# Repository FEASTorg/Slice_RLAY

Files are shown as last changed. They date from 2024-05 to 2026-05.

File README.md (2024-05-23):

<div align="center">
  <!-- Title: -->
  <a href="https://github.com/uwo-fast">
    
  </a>
  <h2><a href="https://github.com/uwo-fast/Slice_RLAY"> Slice RLAY </a></h2>
  <!-- Labels: -->
  <!-- First row: -->
  <a href="https://github.com/uwo-fast/.github/blob/main/collaborating.md">
    
  </a>
  <a href="https://github.com/uwo-fast/.github/blob/main/contributing.md">
    
  </a>
  <a href="https://www.appropedia.org/Category:FAST_literature_reviews">
    
  </a>
  <a href="https://certification.oshwa.org/">
    
    <!-- img src="https://img.shields.io/badge/OSHWA-Certified-darkgreen?style=flat-square" height="20" alt="OSHWA" -->       <!-- img src="https://img.shields.io/badge/OSHWA-Pending-darkorange?style=flat-square" height="20" alt="OSHWA" -->
  </a>
  <a href="https://osf.io/">
    
  </a>
  <a href="https://doi.org">
    
  </a>
  <!-- Second row: -->
  <br>
  <a href="https://github.com/uwo-fast/Slice_RLAY/blob/main/LICENSE">
    
  </a>
  <a href="https://github.com/uwo-fast/Slice_RLAY">
    
  </a>
  <a href="https://github.com/uwo-fast/Slice_RLAY/issues">
    
  </a>
  <a href="https://github.com/uwo-fast/Slice_RLAY/network/members">
    
  </a>
  <a href="https://github.com/uwo-fast/Slice_RLAY/stargazers">
    
  </a>
  <!-- Short description: -->
  <h3>4-Channel Relay Slice for BREAD.</h3>
</div>

## Introduction
[Provide a brief introduction to the project, including the motivation and goals. Explain the significance and context of the research.]

## Project Overview
[Describe the project in more detail. This section can be split into subsections if necessary.]

## Installation
[Provide instructions for installing any necessary software or hardware components.]

## Usage
[Explain how to use the project. Include examples and screenshots if applicable.]

### Basic Usage
[Provide basic usage instructions.]

### Advanced Usage
[Provide advanced usage instructions, including any optional features or configurations.]

## Documentation
[Link to the detailed documentation if available. Provide instructions on how to access and navigate the documentation.]

## Contributing
[Explain how others can contribute to the project. Include guidelines for submitting issues, pull requests, and any coding standards.]

### Code of Conduct
[Link to the project's code of conduct if available.]

## License
[State the license under which the project is distributed. Include a link to the full license text.]

## Acknowledgements
[Acknowledge any contributors, collaborators, funding sources, or organizations that supported the project.]

## Contact
[Provide contact information for the project maintainer(s) or lead researcher(s). Include an email address or a link to a contact form.]

---

<div align="center">
  <p>
    
    
  </p>
</div>

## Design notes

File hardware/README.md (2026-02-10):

# Broadly Reconfigurable and Expandable Automation Device (BREAD) -- Slice Datasheet: **Relay** Slice (SLC-**RLAY**)

## Short Device Description

This device controls 4 relay channels via the Arduino, and receives
analog signals (optionally) as feedback.

## Quick Information

Device at a Glance

---

Short title Relay Slice
Part \# SLC-RLAY
Repository Link Link to OSF or other repository
Academic Paper DOI DOI link to published paper
Device Cost Monetary cost of the device
Assembly Difficulty Medium. Millable.
Application Area Controls, Power Monitoring

---

Device Connections

J2 -- Relay Output 1

---

Pin \# Description Rating
1 Normally closed switch of relay 277 VAC, 30V DC, 3A
2 Normally open switch of relay 277 VAC, 30V DC, 10A AC, 5A DC
3 Common pin N/A

---

J2 -- Relay Output 2

---

Pin \# Description Rating
1 Normally closed switch of relay 277 VAC, 30V DC, 3A
2 Normally open switch of relay 277 VAC, 30V DC, 10A AC, 5A DC
3 Common pin N/A

---

J2 -- Relay Output 3

---

Pin \# Description Rating
1 Normally closed switch of relay 277 VAC, 30V DC, 3A
2 Normally open switch of relay 277 VAC, 30V DC, 10A AC, 5A DC
3 Common pin N/A

---

J2 -- Relay Output 4

---

Pin \# Description Rating
1 Normally closed switch of relay 277 VAC, 30V DC, 3A
2 Normally open switch of relay 277 VAC, 30V DC, 10A AC, 5A DC
3 Common pin N/A

---

## Commands

---

**Write Switch(es) **(no significant returns)  
 **Byte**: Address **Bit**: 1 **Float: **Target Temp **Float: **Ramp Rate (d/m)
**Timed Write** (no significant returns)  
 **Byte**: Address **Bit**: 0 **Float: **0 **Float: **0
Analog Read (Returns selected voltages from analog feedback)

---

## Schematic

## Bill of Materials

---

Designator Description Quantity Cost / part URL
U1-4 Optocouplers 4 0.51 <https://www.digikey.com/short/5fmc702d>
RV1-4 10k Trimmer Potentiometer 4 4.16 <https://www.digikey.com/short/ftm98v7t>
R1-4 1k 1206 Packaging Resistor 4 0.1 <https://www.digikey.com/short/d1dmzmbb>
K1-4 G5Q1 SPDT Relay 4 1.52 <https://www.digikey.com/short/vj4jr0vq>
J6 01x04 1/10" Pitch Terminal Block 1 2.75 <https://www.digikey.com/short/rnm0hhhn>
J2-5 01x03 1/10" Pitch Terminal Block 4 2.06 <https://www.digikey.com/short/71d77cj2>
D5-8 5.1V Zener Diode 4 0.22 <https://www.digikey.com/short/tvbtwpmt>
D1-4 Standard THT Diode 4 0.21 <https://www.digikey.com/short/tp4mrn5q>
C1-2 10 µF 1206 Packaging Ceramic Capacitor 4 0.64 <https://www.digikey.com/short/2ffb0248>
A1 Arduino Nano 1 22.00 <https://www.digikey.com/en/products/detail/arduino/A000005/2638989>
J1 01x10 Female Header Pins 1 0.79 <https://www.digikey.com/short/23bfwwjh>

---

## Construction & Fabrication

List any tools that are required and short guide on the order which
parts should be soldered / assembled. Be sure to note any specialized
methods and point out components that may easily be soldered in the
incorrect orientation. Additionally include at least one picture of the
assembled board (include both sides if there are components on both
sides).

\[Image of the assembled Circuit Board\]

Fig #. Subtitle should go here.

## Configuration & Calibration

Include a list of default jumper and potentiometer positions:

Hardware Positions

- Turn P1 to be roughly 50%
- Turn P2 to be completely closed (turn clockwise until potentiometer
  clicks)
- Place a jumper to short out J3. Etc...

Detail any key parameters the end-user may want to adjust in the
firmware, and if there are any special instructions before programming
the Slice.

Tools Required For Calibration

- An oscilloscope with at least 15Mhz sampling
- A multimeter. Etc...

List all of the tools / instruments required for calibration. Provide a
detailed & step by step guide on how to calibrate (or validate) each
unique type of channel on the card. Include what variables in the
firmware may need to be adjusted (and when). Attach a wiring diagram for
each relevant calibration circuit.

\[Image of the calibration circuit\]

Fig #. Subtitle should go here.

## Usage & Constraints

List the relevant constraints for each type of channel on the card.
These parameters may be quantities like max current, max voltage,
frequency, sampling frequency, etc.

List an example wiring diagram of the slice in use, as well as some
suggested applications

\[Image of the example usage wiring diagram\]

Fig #. Subtitle should go here.

## General Comments on Slice

This section is intended as a catch-all for any topics that are relevant
to the Slice that don't fit in any other category.

## Revision Notes

- Rev 0 -- Initial document release (DATE HERE)

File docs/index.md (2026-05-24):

---
title: "Slice RLAY Documentation"
description: "Overview and entry page for Slice RLAY project documentation."
nav_exclude: true
---

Welcome to the Slice RLAY project documentation.

## Board Renders

<figure style="display:inline-block; text-align:center; margin:10px;">
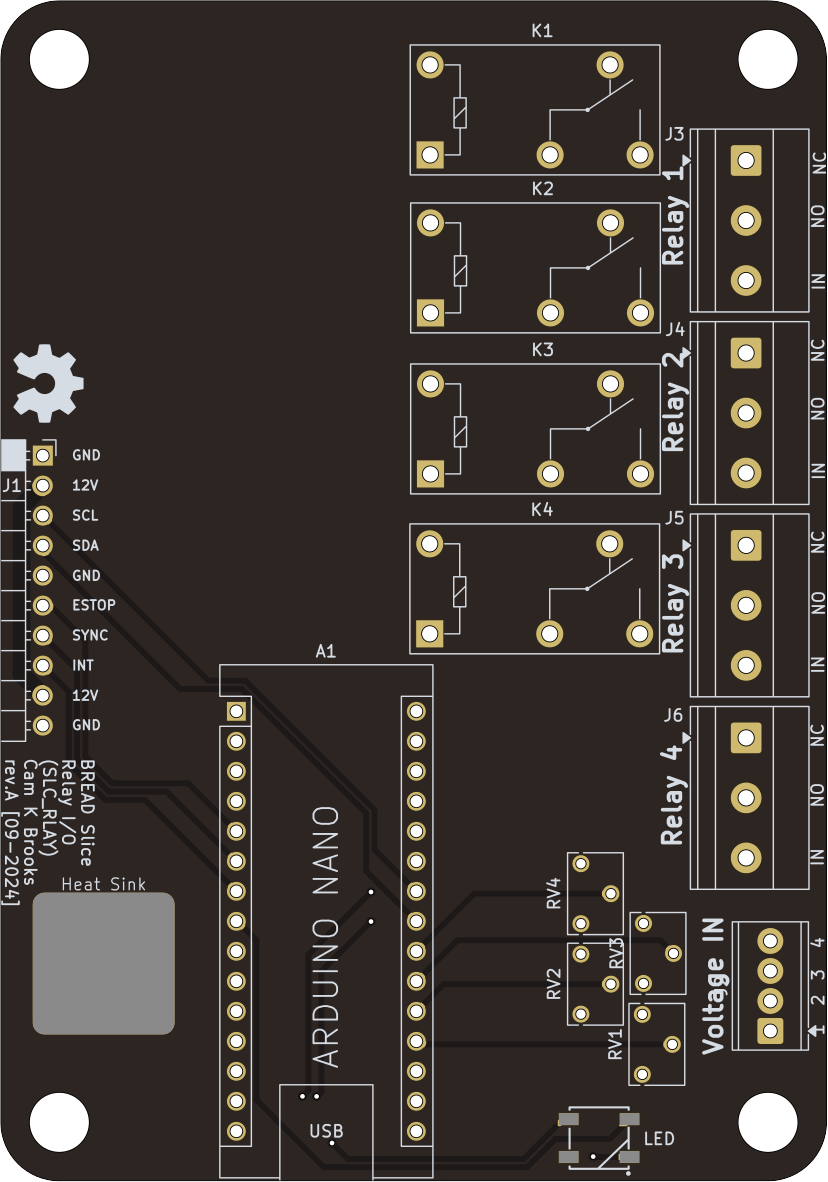
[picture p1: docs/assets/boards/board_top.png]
Board Top
  
  <figcaption>Top</figcaption>
</figure>

<figure style="display:inline-block; text-align:center; margin:10px;">
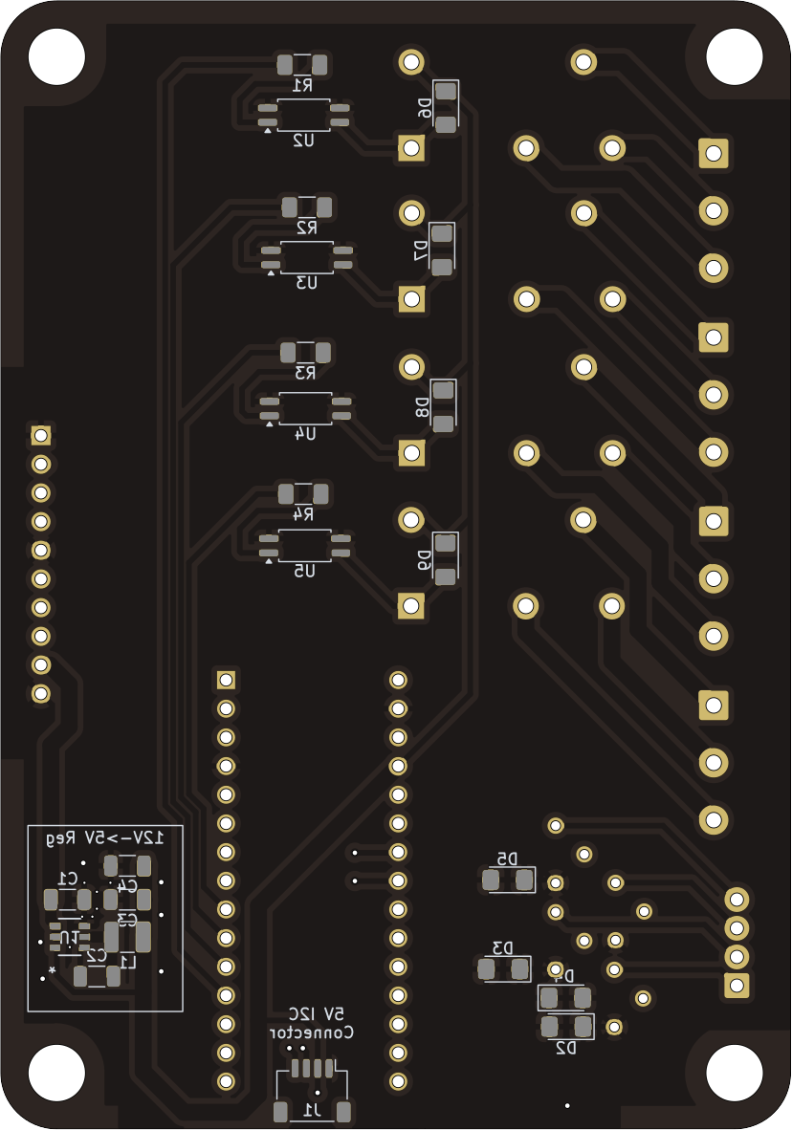
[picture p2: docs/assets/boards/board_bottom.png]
Board Bottom
  
  <figcaption>Bottom</figcaption>
</figure>

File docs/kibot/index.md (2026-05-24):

Slice RLAY KiBot Outputs
============================

Generated: 2026-05-24 at 16:19:26 UTC

## Artifacts

- [Schematic.pdf](./Schematic.pdf)
- [PCB.pdf](./PCB.pdf)
- [kibot.log](./kibot.log)
- [BREAD_Slice-bom.html](./BREAD_Slice-bom.html)
- [BREAD_Slice-ibom.html](./BREAD_Slice-ibom.html)

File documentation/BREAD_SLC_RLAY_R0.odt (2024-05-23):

# Broadly Reconfigurable and Expandable Automation Device (BREAD) – Slice Datasheet: Relay Slice (SLC-RLAY)

By: Nicholas Whisman (ngwhisma@mtu.edu) – Revision 0, on 17. May 2021

## Short Device Description

This device controls 4 relay channels via the Arduino, and receives analog signals (optionally) as feedback.

## Quick Information

Device at a Glance

Short title | Relay Slice
Part # | SLC-RLAY
Repository Link | Link to OSF or other repository
Academic Paper DOI | DOI link to published paper
Device Cost | Monetary cost of the device
Assembly Difficulty | Medium. Millable.
Application Area | Controls, Power Monitoring

Device Connections

J2 – Relay Output 1

Pin # | Description | Rating
1 | Normally closed switch of relay | 277 VAC, 30V DC, 3A
2 | Normally open switch of relay | 277 VAC, 30V DC, 10A AC, 5A DC
3 | Common pin | N/A

J2 – Relay Output 2

Pin # | Description | Rating
1 | Normally closed switch of relay | 277 VAC, 30V DC, 3A
2 | Normally open switch of relay | 277 VAC, 30V DC, 10A AC, 5A DC
3 | Common pin | N/A

J2 – Relay Output 3

Pin # | Description | Rating
1 | Normally closed switch of relay | 277 VAC, 30V DC, 3A
2 | Normally open switch of relay | 277 VAC, 30V DC, 10A AC, 5A DC
3 | Common pin | N/A

J2 – Relay Output 4

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

## Commands

Write Switch(es) (no significant returns)
Byte: Address | Bit: 1 | Float: Target Temp | Float: Ramp Rate (d/m)
Timed Write (no significant returns)
Byte: Address | Bit: 0 | Float: 0 | Float: 0
Analog Read (Returns selected voltages from analog feedback)

## Schematic

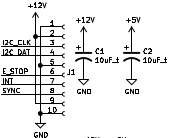
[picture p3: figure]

Figure 1: BREAD Connection Port + Power Capacitors

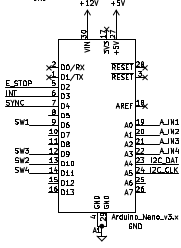
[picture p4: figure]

Figure 2: Arduino Nano

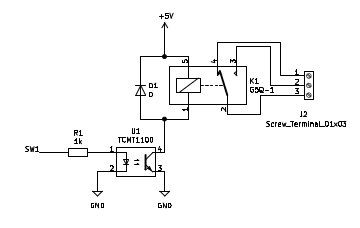
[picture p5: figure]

Figure 3: One of Four Relay Channels

Figure 4: One of Four Analog Input Paths

Figure 5: Feedback Input Port

## Bill of Materials

Designator | Description | Quantity | Cost / part | URL
U1-4 | Optocouplers | 4 | 0.51 | https://www.digikey.com/short/5fmc702d
RV1-4 | 10k Trimmer Potentiometer | 4 | 4.16 | https://www.digikey.com/short/ftm98v7t
R1-4 | 1k 1206 Packaging Resistor | 4 | 0.1 | https://www.digikey.com/short/d1dmzmbb
K1-4 | G5Q1 SPDT Relay | 4 | 1.52 | https://www.digikey.com/short/vj4jr0vq
J6 | 01x04 1/10” Pitch Terminal Block | 1 | 2.75 | https://www.digikey.com/short/rnm0hhhn
J2-5 | 01x03 1/10” Pitch Terminal Block | 4 | 2.06 | https://www.digikey.com/short/71d77cj2
D5-8 | 5.1V Zener Diode | 4 | 0.22 | https://www.digikey.com/short/tvbtwpmt
D1-4 | Standard THT Diode | 4 | 0.21 | https://www.digikey.com/short/tp4mrn5q
C1-2 | 10 µF 1206 Packaging Ceramic Capacitor | 4 | 0.64 | https://www.digikey.com/short/2ffb0248
A1 | Arduino Nano | 1 | 22.00 | https://www.digikey.com/en/products/detail/arduino/A000005/2638989
J1 | 01x10 Female Header Pins | 1 | 0.79 | https://www.digikey.com/short/23bfwwjh

## Construction & Fabrication

List any tools that are required and short guide on the order which parts should be soldered / assembled. Be sure to note any specialized methods and point out components that may easily be soldered in the incorrect orientation. Additionally include at least one picture of the assembled board (include both sides if there are components on both sides).

[Image of the assembled Circuit Board]

Fig #. Subtitle should go here.

## Configuration & Calibration

Include a list of default jumper and potentiometer positions:

Hardware Positions

- Turn P1 to be roughly 50%
- Turn P2 to be completely closed (turn clockwise until potentiometer clicks)
- Place a jumper to short out J3. Etc…

Detail any key parameters the end-user may want to adjust in the firmware, and if there are any special instructions before programming the Slice.

Tools Required For Calibration

- An oscilloscope with at least 15Mhz sampling
- A multimeter. Etc…

List all of the tools / instruments required for calibration. Provide a detailed & step by step guide on how to calibrate (or validate) each unique type of channel on the card. Include what variables in the firmware may need to be adjusted (and when). Attach a wiring diagram for each relevant calibration circuit.

[Image of the calibration circuit]

Fig #. Subtitle should go here.

## Usage & Constraints

List the relevant constraints for each type of channel on the card. These parameters may be quantities like max current, max voltage, frequency, sampling frequency, etc.

List an example wiring diagram of the slice in use, as well as some suggested applications

[Image of the example usage wiring diagram]

Fig #. Subtitle should go here.

## General Comments on Slice

This section is intended as a catch-all for any topics that are relevant to the Slice that don’t fit in any other category.

## Revision Notes

- Rev 0 – Initial document release (DATE HERE)

SLC-RLAY Datasheet – Revision 0

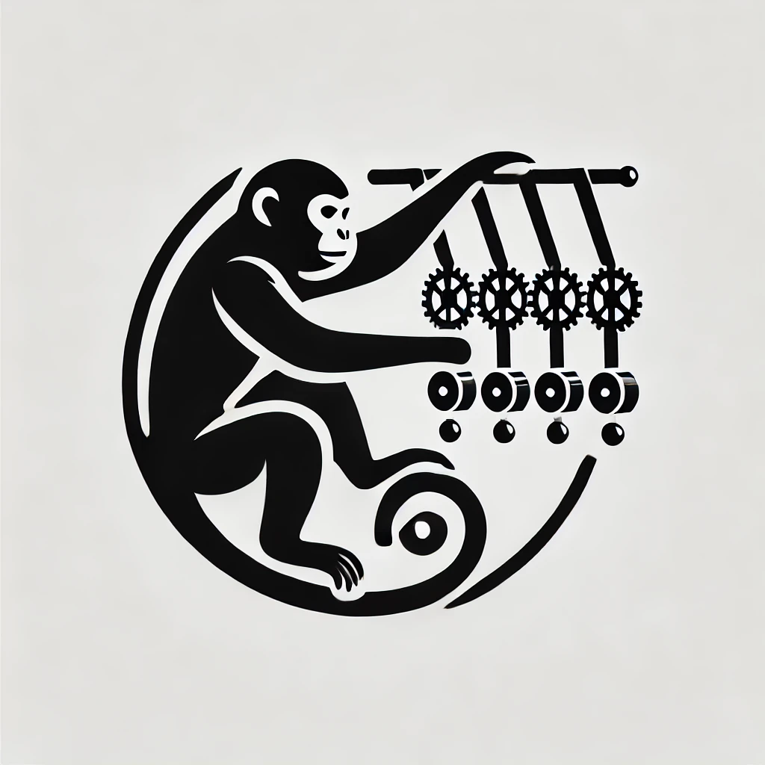
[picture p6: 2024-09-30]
hardware/rhesus-macaque-monkey-4levers.png

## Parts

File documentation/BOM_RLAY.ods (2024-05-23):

Id | Designator | Package | Quantity | Designation | Supplier and ref | Cost per part | Total
1 | U2,U4,U3,U1 | SOP-4_4.4x2.6mm_P1.27mm | 4 | EL3H7 | https://www.digikey.ca/en/products/detail/everlight-electronics-co-ltd/EL3H7-B-TA-VG/2675688 | $0.47 | $1.88
2 | RV4,RV3,RV2,RV1 | Potentiometer_Bourns_3266W_Vertical | 4 | 10k | https://www.digikey.ca/en/products/detail/bourns-inc/3266W-1-103LF/1087907 | $5.59 | $22.36
3 | R4,R3,R2,R1 | R_1206_3216Metric_Pad1.30x1.75mm_HandSolder | 4 | 1k | https://www.digikey.ca/en/products/detail/stackpole-electronics-inc/RMCF1206FT1K00/1759616 | $6.21 | $24.84
4 | K4,K3,K2,K1 | Relay_SPDT_Omron-G5Q-1 | 4 | G5Q-1 | https://www.digikey.ca/en/products/detail/omron-electronics-inc-emc-div/G5Q-1-DC5/1815726?productid= | $1.66 | $6.64
5 | J6 | TerminalBlock_TE_282834-4_1x04_P2.54mm_Horizontal | 1 | Screw_Terminal_01x04 | https://www.digikey.ca/en/products/detail/on-shore-technology-inc/OSTVN04A150/1588864 | $2.01 | $2.01
6 | J5,J4,J3,J2 | TerminalBlock_TE_282834-3_1x03_P2.54mm_Horizontal | 4 | Screw_Terminal_01x03 | https://www.digikey.ca/en/products/detail/on-shore-technology-inc/OSTVN03A150/1588863 | $1.51 | $6.04
7 | D8,D7,D6,D5 | D_1206_3216Metric_Pad1.42x1.75mm_HandSolder | 4 | D_Zener | https://www.digikey.ca/en/products/detail/diodes-incorporated/BZT52C15-7-F/755469 | $0.32 | $1.28
8 | D4,D3,D2,D1 | D_1206_3216Metric_Pad1.42x1.75mm_HandSolder | 4 | D | https://www.digikey.ca/en/products/detail/kyocera-avx/SD1206S020S1R0/3749491 | $0.60 | $2.40
9 | C2,C1 | C_2312 | 2 | 10uF_t | https://www.digikey.ca/short/qfrbqfhd | $0.81 | $1.62
12 | A1 | Arduino_Nano | 1 | Arduino_Nano_v3.x | https://www.digikey.ca/en/products/detail/arduino/A000005/2638989 | $9.58 | $9.58
13 | J1 | PinSocket_1x10_P2.54mm_Horizontal | 1 | Conn_01x10_Female | https://www.digikey.ca/en/products/detail/sullins-connector-solutions/PPPC101LGBN-RC/775943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 | $1.10 | $1.10
 |  |  |  |  |  | Total | $79.75

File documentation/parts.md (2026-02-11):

# Parts Dump

- Phoenix Contact - x8 - Fixed Terminal Blocks PTSA 0.5/ 8-2.5-F
  - [Mouser](https://mou.sr/4rJ66VM)
- Phoenix Contact - x3 - Fixed Terminal Blocks LPTA 2,5/ 3-5,0
  - [Mouser](https://mou.sr/4bMrh4H)

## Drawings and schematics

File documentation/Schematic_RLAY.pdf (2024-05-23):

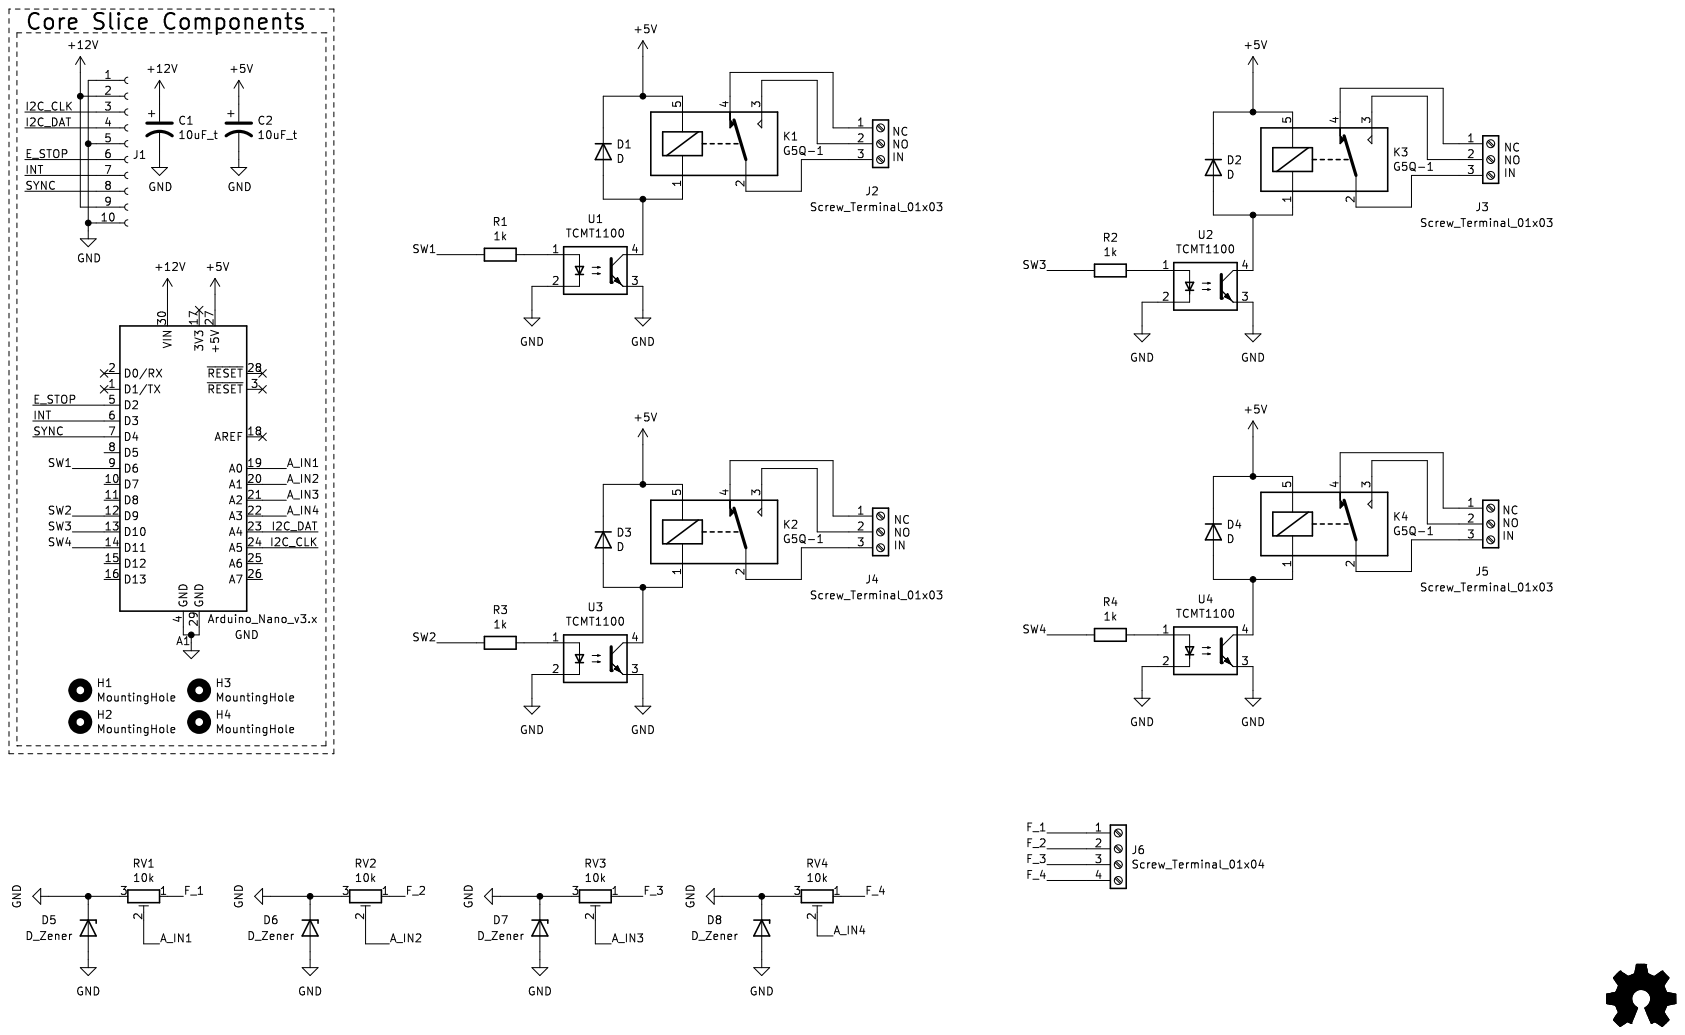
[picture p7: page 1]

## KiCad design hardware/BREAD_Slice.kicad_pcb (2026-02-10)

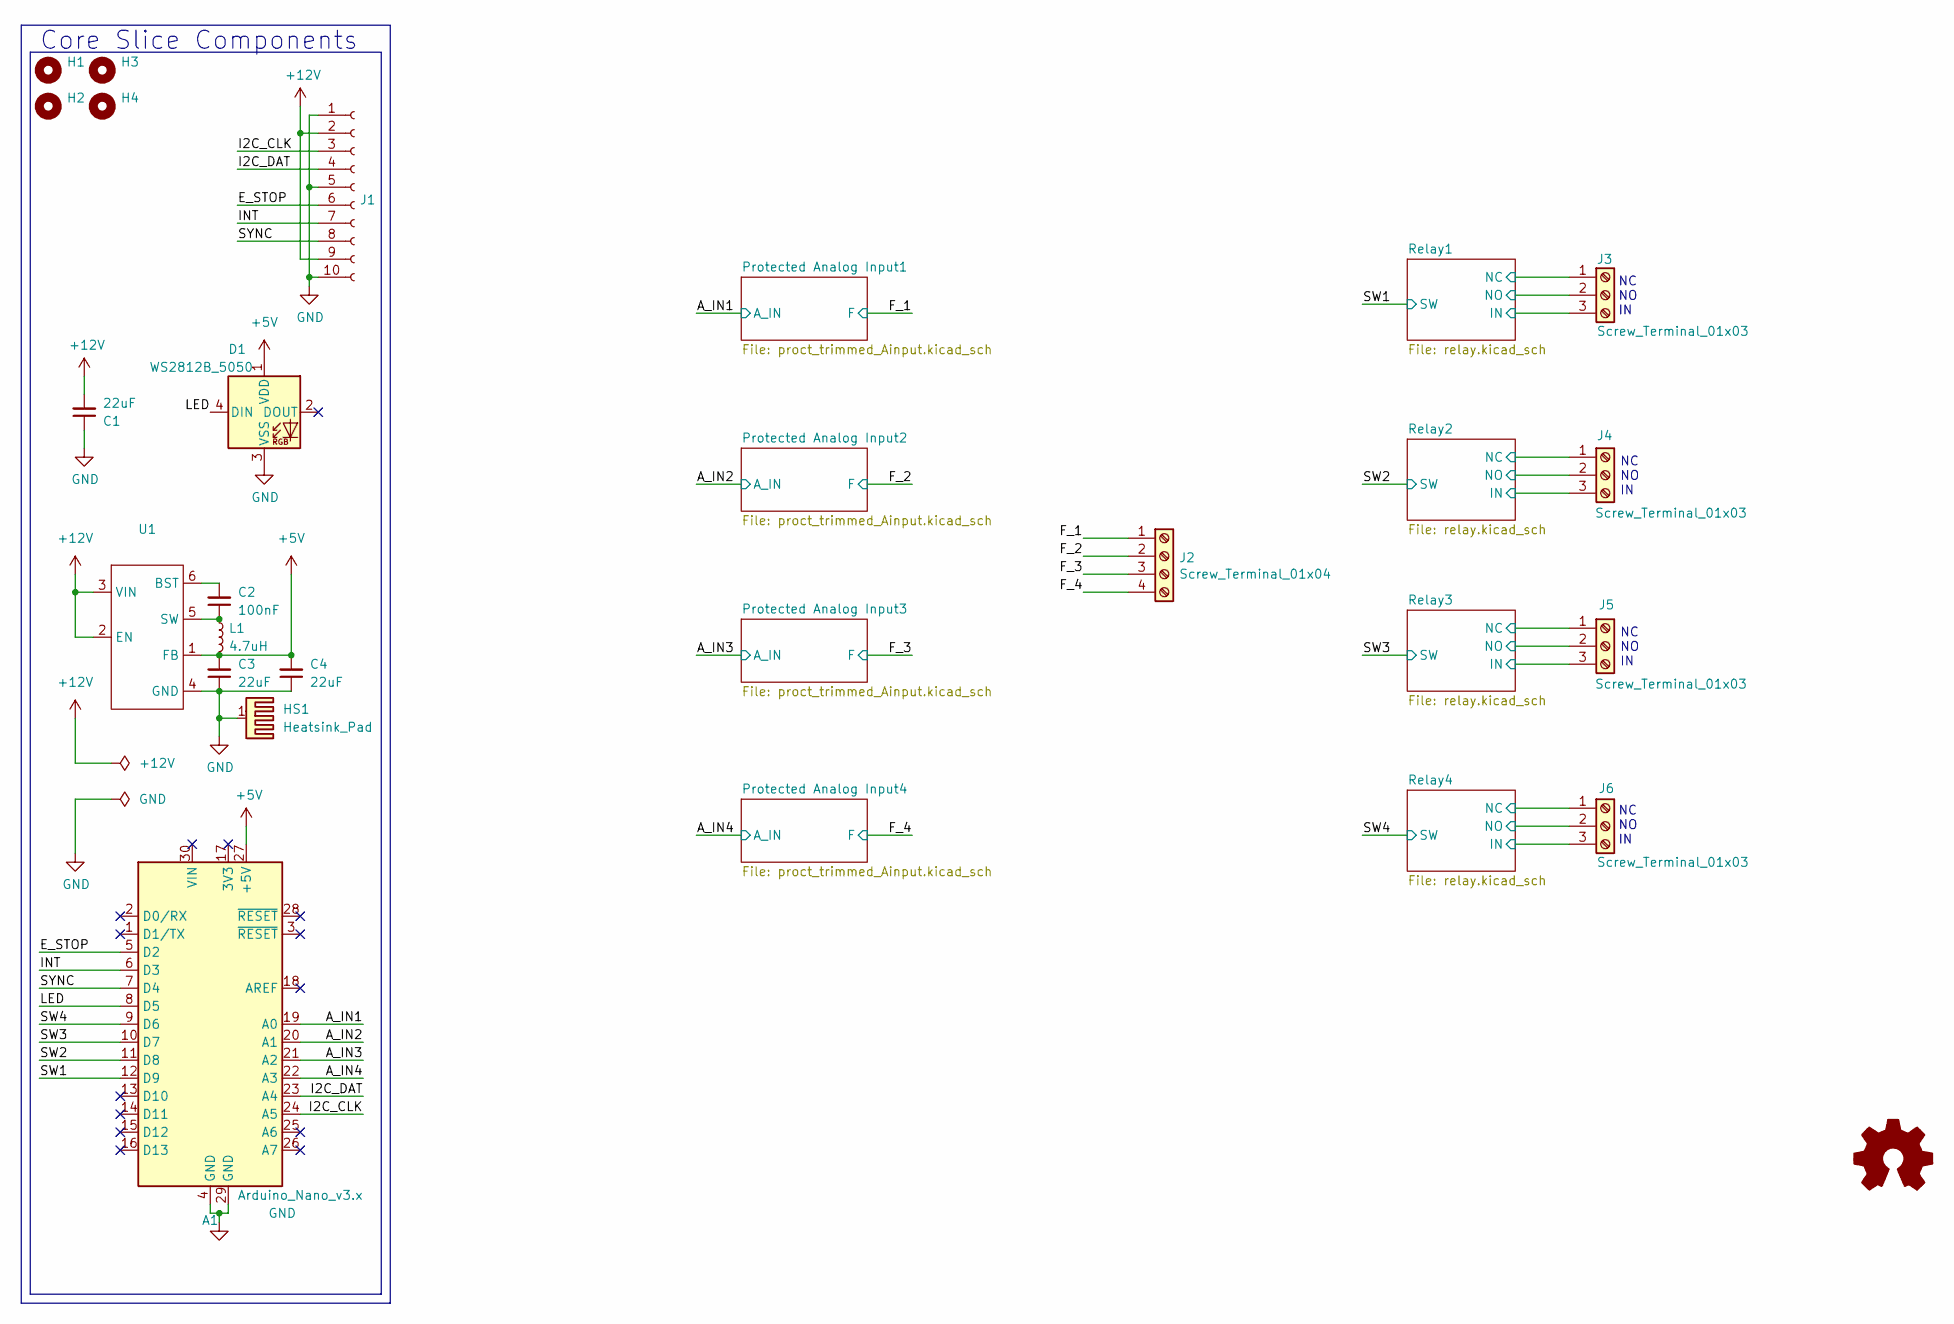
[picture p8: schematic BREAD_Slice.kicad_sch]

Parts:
A1: Arduino_Nano_v3.x; Arduino_Nano
C1, C3, C4: 22uF; C_1206_3216Metric
C2: 100nF; C_1206_3216Metric
D1: WS2812B_5050; WS2812-5050-4PIN
H1, H2, H3, H4: MountingHole; MountingHole_5mm
HS1: Heatsink_Pad; Thermal Pad
J1: Conn_01x10_Female; PinSocket_1x10_P2.54mm_Horizontal
J2: Screw_Terminal_01x04; TerminalBlock_Phoenix_MPT-0,5-4-2.54_1x04_P2.54mm_Horizontal
J3, J4, J5, J6: Screw_Terminal_01x03; TerminalBlock_Phoenix_MKDS-1,5-3-5.08_1x03_P5.08mm_Horizont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
L1: 4.7uH; L_1210_3225Metric
U1: SOIC_05WU-7_DIO

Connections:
+5V: A1.27 (+5V), C3.2, C4.2, D1.1 (VDD), L1.2, U1.1 (FB); also elsewhere on the board
+12V: C1.2, J1.2, J1.9, U1.2 (EN), U1.3 (VIN)
/A_IN1: A1.19 (A0); also elsewhere on the board
/A_IN2: A1.20 (A1); also elsewhere on the board
/A_IN3: A1.21 (A2); also elsewhere on the board
/A_IN4: A1.22 (A3); also elsewhere on the board
/E_STOP: A1.5 (D2), J1.6
/F_1: J2.1; also elsewhere on the board
/F_2: J2.2; also elsewhere on the board
/F_3: J2.3; also elsewhere on the board
/F_4: J2.4; also elsewhere on the board
/I2C_CLK: A1.24 (A5), J1.3; also elsewhere on the board
/I2C_DAT: A1.23 (A4), J1.4; also elsewhere on the board
/INT: A1.6 (D3), J1.7
/LED: A1.8 (D5), D1.4 (DIN)
/Relay1/IN: J3.3; also elsewhere on the board
/Relay1/NC: J3.1; also elsewhere on the board
/Relay1/NO: J3.2; also elsewhere on the board
/Relay2/IN: J4.3; also elsewhere on the board
/Relay2/NC: J4.1; also elsewhere on the board
/Relay2/NO: J4.2; also elsewhere on the board
/Relay3/IN: J5.3; also elsewhere on the board
/Relay3/NC: J5.1; also elsewhere on the board
/Relay3/NO: J5.2; also elsewhere on the board
/Relay4/IN: J6.3; also elsewhere on the board
/Relay4/NC: J6.1; also elsewhere on the board
/Relay4/NO: J6.2; also elsewhere on the board
/SW1: A1.12 (D9); also elsewhere on the board
/SW2: A1.11 (D8); also elsewhere on the board
/SW3: A1.10 (D7); also elsewhere on the board
/SW4: A1.9 (D6); also elsewhere on the board
/SYNC: A1.7 (D4), J1.8
GND: A1.4 (GND), A1.29 (GND), C1.1, C3.1, C4.1, D1.3 (VSS), HS1.1, J1.1, J1.5, J1.10, U1.4 (GND); also elsewhere on the board
unnamed: C2.2, U1.6 (BST)
unnamed: C2.1, L1.1, U1.5 (SW)

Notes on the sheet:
NC NO IN
Core Slice Components

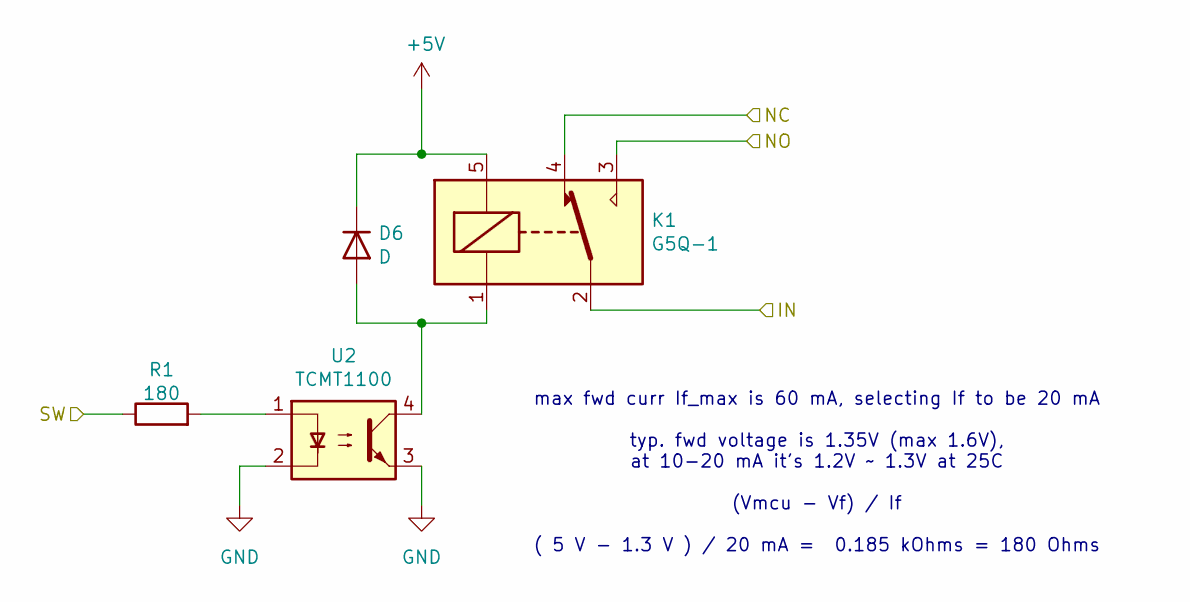
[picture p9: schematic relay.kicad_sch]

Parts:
D6: D; D_1206_3216Metric_Pad1.42x1.75mm_HandSolder
K1: G5Q-1; Relay_SPDT_Omron-G5Q-1
R1: 180; R_1206_3216Metric_Pad1.30x1.75mm_HandSolder
U2: TCMT1100; SOP-4_4.4x2.6mm_P1.27mm

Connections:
+5V: D6.1 (K), K1.5; also elsewhere on the board
/Relay1/IN: K1.2; also elsewhere on the board
/Relay1/NC: K1.4; also elsewhere on the board
/Relay1/NO: K1.3; also elsewhere on the board
/SW1: R1.1; also elsewhere on the board
GND: U2.2, U2.3; also elsewhere on the board
unnamed: D6.2 (A), K1.1, U2.4
unnamed: R1.2, U2.1

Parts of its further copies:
D7, D8, D9: D; D_1206_3216Metric_Pad1.42x1.75mm_HandSolder
K2, K3, K4: G5Q-1; Relay_SPDT_Omron-G5Q-1
R2, R3, R4: 180; R_1206_3216Metric_Pad1.30x1.75mm_HandSolder
U3, U4, U5: TCMT1100; SOP-4_4.4x2.6mm_P1.27mm

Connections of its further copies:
+5V: D7.1 (K), D8.1 (K), D9.1 (K), K2.5, K3.5, K4.5; also elsewhere on the board
/Relay2/IN: K2.2; also elsewhere on the board
/Relay2/NC: K2.4; also elsewhere on the board
/Relay2/NO: K2.3; also elsewhere on the board
/Relay3/IN: K3.2; also elsewhere on the board
/Relay3/NC: K3.4; also elsewhere on the board
/Relay3/NO: K3.3; also elsewhere on the board
/Relay4/IN: K4.2; also elsewhere on the board
/Relay4/NC: K4.4; also elsewhere on the board
/Relay4/NO: K4.3; also elsewhere on the board
/SW2: R2.1; also elsewhere on the board
/SW3: R3.1; also elsewhere on the board
/SW4: R4.1; also elsewhere on the board
GND: U3.2, U3.3, U4.2, U4.3, U5.2, U5.3; also elsewhere on the board
unnamed: D7.2 (A), K2.1, U3.4
unnamed: D8.2 (A), K3.1, U4.4
unnamed: D9.2 (A), K4.1, U5.4
unnamed: R2.2, U3.1
unnamed: R3.2, U4.1
unnamed: R4.2, U5.1

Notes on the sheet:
max fwd curr If_max is 60 mA, selecting If to be 20 mA typ. fwd voltage is 1.35V (max 1.6V), at 10-20 mA it's 1.2V ~ 1.3V at 25C (Vmcu - Vf) / If ( 5 V - 1.3 V ) / 20 mA = 0.185 kOhms = 180 Ohms

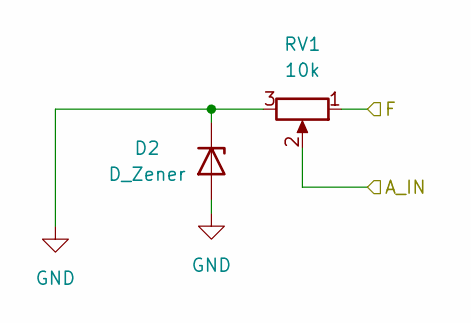
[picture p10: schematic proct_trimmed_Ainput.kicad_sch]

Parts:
D2: D_Zener; D_1206_3216Metric_Pad1.42x1.75mm_HandSolder
RV1: 10k; Potentiometer_Bourns_3266W_Vertical

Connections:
/A_IN1: RV1.2; also elsewhere on the board
/F_1: RV1.1; also elsewhere on the board
GND: D2.1 (K), D2.2 (A), RV1.3; also elsewhere on the board

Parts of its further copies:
D3, D4, D5: D_Zener; D_1206_3216Metric_Pad1.42x1.75mm_HandSolder
RV2, RV3, RV4: 10k; Potentiometer_Bourns_3266W_Vertical

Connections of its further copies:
/A_IN2: RV2.2; also elsewhere on the board
/A_IN3: RV3.2; also elsewhere on the board
/A_IN4: RV4.2; also elsewhere on the board
/F_2: RV2.1; also elsewhere on the board
/F_3: RV3.1; also elsewhere on the board
/F_4: RV4.1; also elsewhere on the board
GND: D3.1 (K), D3.2 (A), D4.1 (K), D4.2 (A), D5.1 (K), D5.2 (A), RV2.3, RV3.3, RV4.3; also elsewhere on the board

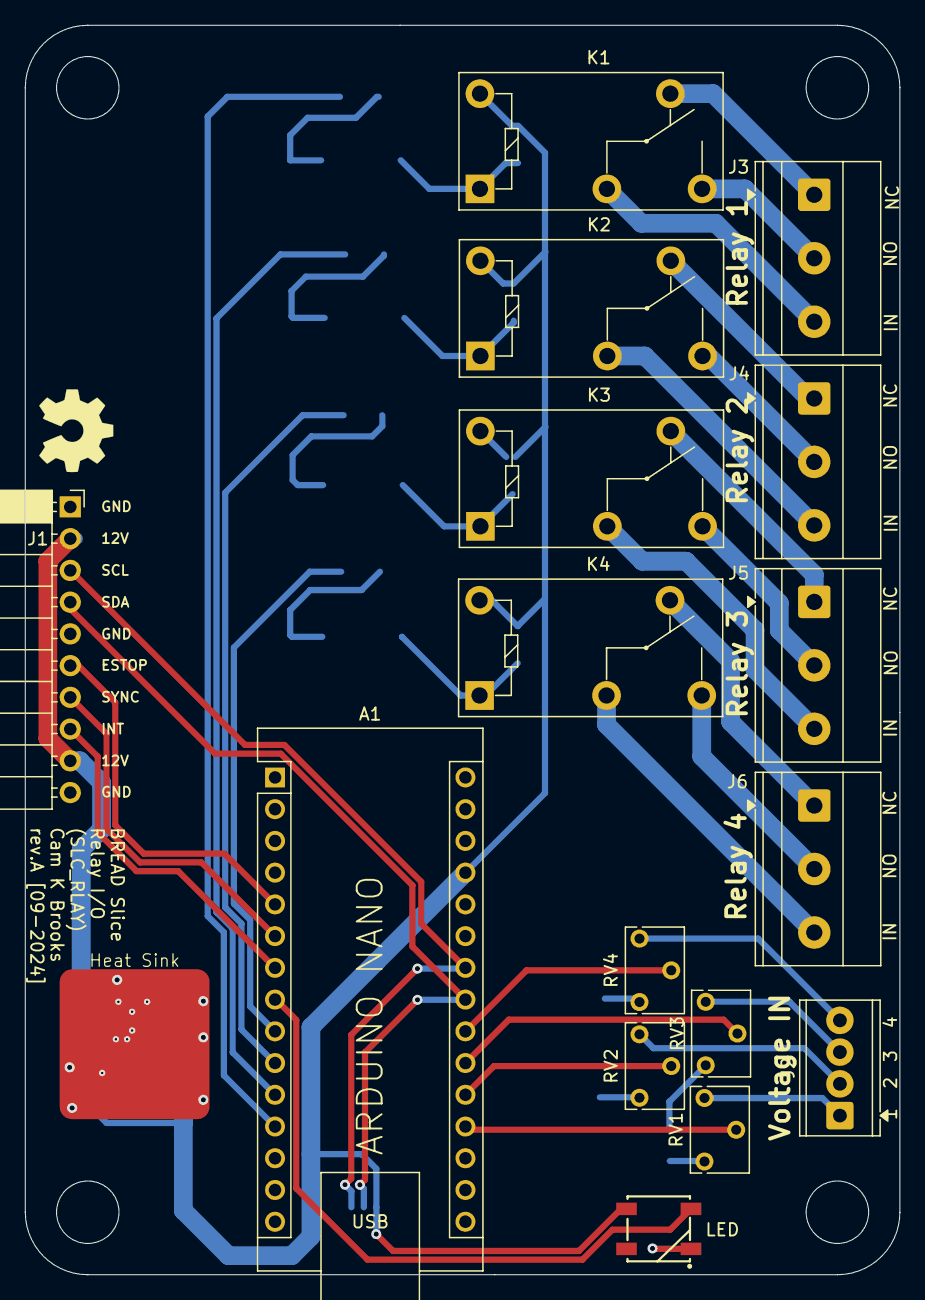
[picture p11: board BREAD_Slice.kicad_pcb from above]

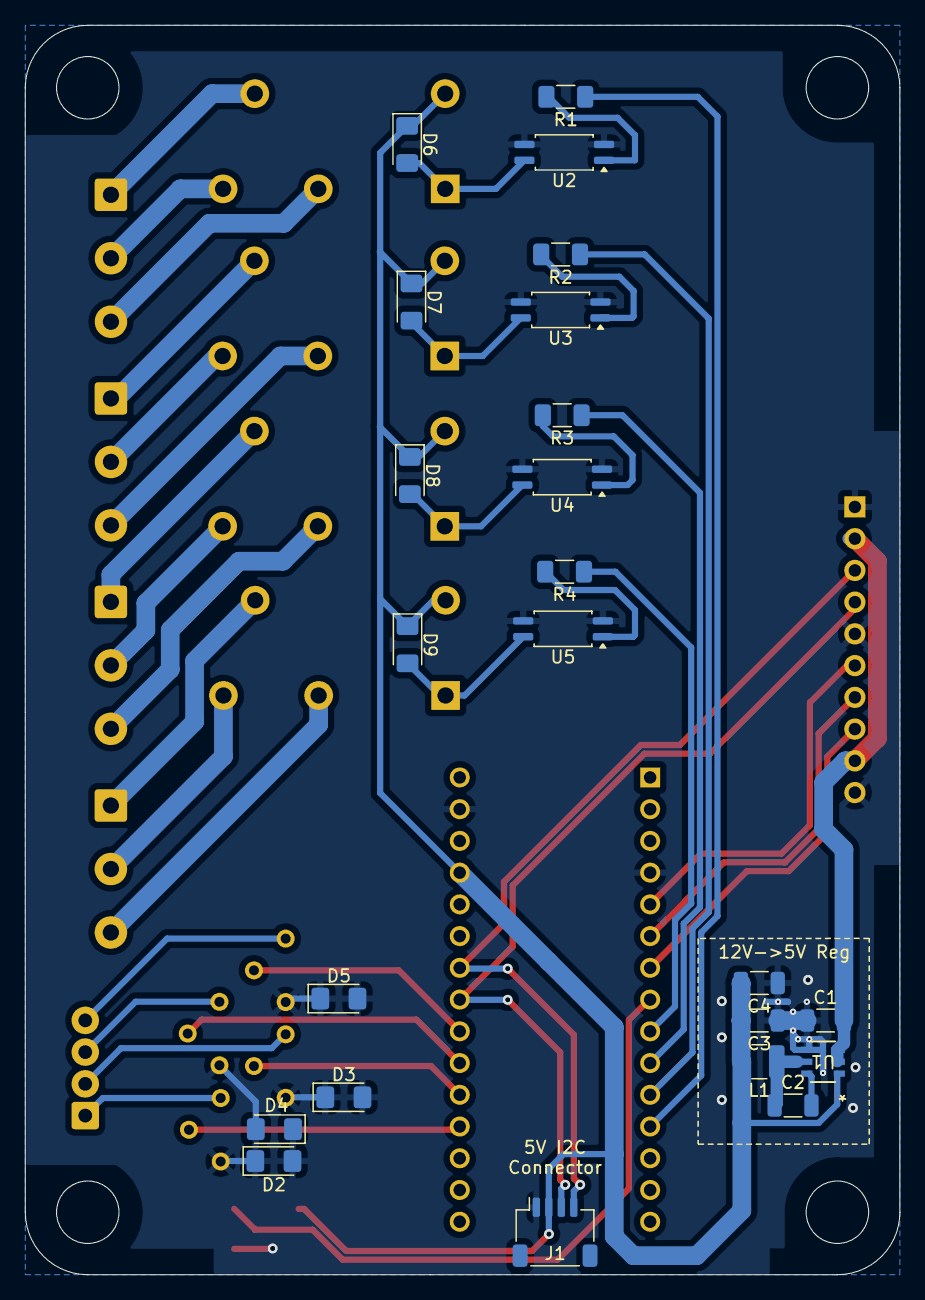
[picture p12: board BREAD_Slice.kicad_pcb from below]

Board: 2 copper layers, 70.0 x 100.0 mm, 45 parts (23 on the bottom side), 43 nets.

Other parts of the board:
J1#2: I2C_01x04; JST_SH_SM04B-SRSS-TB_1x04-1MP_P1.00mm_Horizontal
Logo1: Logo_Open_Hardware_Small; OSHW-Symbol_6.7x6mm_SilkScreen

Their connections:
+5V: J1#2.2; also elsewhere on the board
/I2C_CLK: J1#2.4; also elsewhere on the board
/I2C_DAT: J1#2.3; also elsewhere on the board
GND: J1#2.1; also elsewhere on the board

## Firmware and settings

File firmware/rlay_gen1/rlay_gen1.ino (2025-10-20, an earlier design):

/*
  Relay + Analog Input Test
  Control-only via Serial. Non-blocking. Professional split across 3 files.
  Relays: SW1..SW4 → D6, D9, D10, D11
  Analogs: A_IN1..A_IN4 → A0..A3
  Baud: 115200

  Commands (case-insensitive):
    HELP
    PINS
    SET <1-4> <ON|OFF>
    GET <1-4|ALL>
    READ <1-4|ALL>
    REF <volts>
    STREAM <ms|OFF>
*/

#include <Arduino.h>

// === Pins ===
const uint8_t RELAY_PINS[4] = {6, 9, 10, 11};    // SW1..SW4
const uint8_t ANALOG_PINS[4] = {A0, A1, A2, A3}; // A_IN1..A_IN4

// === Config ===
const uint16_t ADC_MAX = 1023;
float g_refVoltage = 11.90f;          // Adjustable via REF command
unsigned long g_streamIntervalMs = 0; // 0 = OFF
const uint32_t BAUD = 115200;

// === State ===
bool g_relays[4] = {false, false, false, false};
unsigned long g_lastStreamAt = 0;

// === Prototypes (implemented across files) ===
void serialCommandInput();
void printHelp();
void printPins();
void printStatus(uint8_t idx); // 1..4
void printStatusAll();
void printRead(uint8_t idx); // 1..4
void printReadAll();
void printCSVAnalogLine();

// === Setup ===
void setup()
{
    Serial.begin(BAUD);
    for (uint8_t i = 0; i < 4; i++)
    {
        pinMode(RELAY_PINS[i], OUTPUT);
        digitalWrite(RELAY_PINS[i], LOW);
        pinMode(ANALOG_PINS[i], INPUT);
    }
    Serial.println(F("READY"));
    Serial.println(F("Type HELP"));
}

// === Loop (non-blocking) ===
void loop()
{
    serialCommandInput();

    if (g_streamIntervalMs > 0)
    {
        const unsigned long now = millis();
        if (now - g_lastStreamAt >= g_streamIntervalMs)
        {
            printCSVAnalogLine();
            g_lastStreamAt = now;
        }
    }
}

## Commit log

2024-08-16 added firmware and the updated PCB with new BREAD format
    [BREAD_Slice-B_Cu.gbr, BREAD_Slice-B_Mask.gbr, BREAD_Slice-B_Paste.gbr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]
2024-09-12 fixed current limiting resistor on optocoupler input
    [relay.kicad_sch]
2024-09-12 changed terminals to meet those of the relays max output with margin
    [BOM_TEMP.ods, BREAD_Slice.kicad_pcb, BREAD_Slice.kicad_sch]
2024-09-30 JLCPCB order rev-A
    [BREAD_Slice-B_Cu.gbr, BREAD_Slice-B_Mask.gbr, BREAD_Slice-B_Paste.gbr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]
2025-10-20 add test script and debug pcb issues with digital line resistor values
    [BREAD_Slice.kicad_sch, proct_trimmed_Ainput.kicad_sch, relay.kicad_sch]
2026-02-10 update to use latest kmlib; needs revision for connectors and ground inputs on analog inputs
    [BREAD_Slice-B_Cu.gbr, BREAD_Slice-B_Mask.gbr, BREAD_Slice-B_Paste.gbr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]
2026-02-11 add connector blocks to parts doc
2026-05-24 📄 KiBot index + board renders (auto)
